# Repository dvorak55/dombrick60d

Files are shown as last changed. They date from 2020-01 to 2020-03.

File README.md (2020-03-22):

# dombrick60d : Dvorak Oriented 60% Keyboard dedicated to Dell
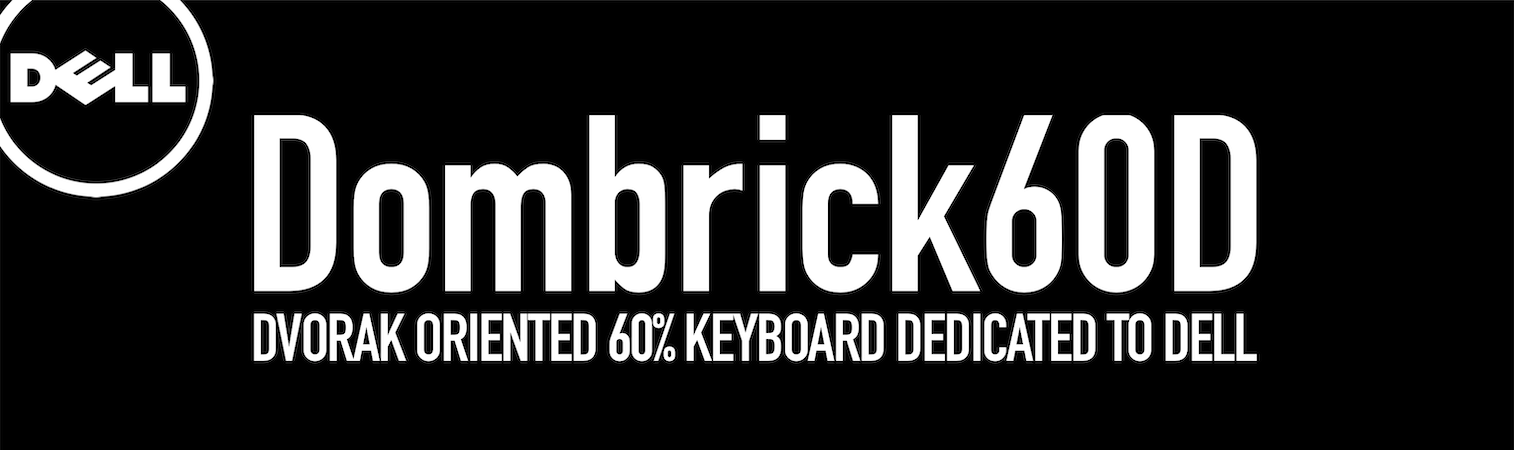
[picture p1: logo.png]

Dombrick60D is self made dvorak oriented keyboard.  
Dombrick60DはDvorak配列志向の自作キーボードです。

"Dombrick" stands for Dvorak Oriented Mechanical Breakthough Remakable Interesting Coolest Keyboard (joke  
Dombrickという名前は「Dvorak志向の革新的で驚くべき大変興味深い最高にクールな機械式キーボード」を表す英単語の頭文字を取って命名しました（笑

Actually, "Dombri" means one of a japanese food style bowl, "ck" means nothing.  
嘘です、Dombriはもちろん日本語の丼を意味しており、ckの二文字はバランスを整えるために付けているだけです。

以下、[DescriptionのPDF](https://github.com/dvorak55/dombrick60d/blob/master/description.pdf)から抜粋

## 概要
Dombrick60DはDvorak配列志向の45%キーボードDombrick45にDellのノートパソコンで採用されていたカーソルキー／PGUP／PGDWを追加、かつマクロ用Chocキーを手前に配置した変態配列キーボードです。

## 特徴
- 横幅14.75U。相変わらずDvorak配列ユーザ志向のキーマップ
- 数字キーが無いのに60%キーボードを名乗る図々しさ
- +と=キーを本来の位置に搭載、カーソルキーもあの位置に搭載
- 最下段の下段(?)にマクロ・ショートカット用のキーを10個搭載
- 一応6.25uスペースバーも選べる(けど作者は使いません)
- モビロンバンドとシリコンマットによるマウント方式は健在だよ! • (最下段の下段以外は)一般的なキーキャップに対応
- DellのPCが使いたくなるPCBシルクデザイン(ロゴを入れただけ)

## キー配列
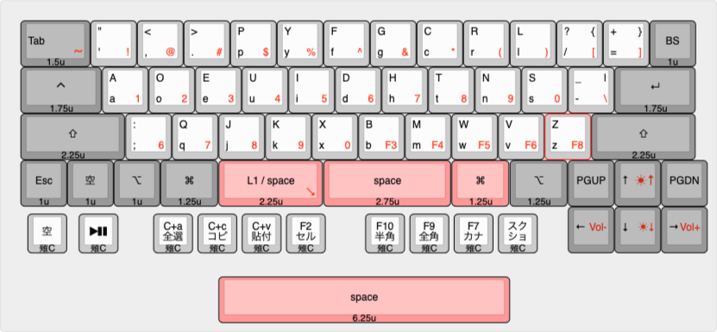
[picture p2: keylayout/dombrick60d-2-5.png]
keymap-of-dombrick60d


最下段のさらに下段（？）の10キーはChoc。Chocなのでスペースキーを押す時に干渉しない、はずなんです。

## Kitに入っている部品
1. PCB 1枚
2. 電子部品(コンデンサ 6個、ダイオード 65個、フューズ 1個、抵抗 6個、ESDダイオード 1個、水晶振動子 1個、リセットスイッチ 1個)
3. MCU(ATmega32U2 1個)
4. USB端子(USB-C 1個)
5. スタビライザー(2Uと6.25Uがそれぞれ 1個ずつ)
6. モビロンゴム(55mm 12本、100mm 6本)
7. シリコンシート(基板サイズ 2枚分)
8. ボトムプレート(厚さ1.5mmステンレス 1枚)

## 別途ご用意頂く部品
1. キースイッチ(Cherry MX互換で5ピンPCBマウント) 53個
2. キースイッチ(Choc) 10個
3. キーキャップ(Cherry MX互換 53個、Choc 10個)
4. USB-Cケーブル

## スペック（実装例）
サイズ：77mm × 253mm × 23mm

重さ　：約560グラム

## スイッチ互換性
Cherry MX互換とALPS(ただし最下段 の下段キーはChoc)

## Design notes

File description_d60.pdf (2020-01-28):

# Dombrick60DはDvorak配列志向の45％キーボード Dombrick45にDellのノートパソコンで採⽤されてい たカーソルキー/PGUP/PGDW追加、かつマクロ⽤ Chocキーを⼿前に配置した変態配列キーボードです

## Dombrick60Dの特徴

### - 横幅14.75U。相変わらずDvorak配列ユーザ志向のキーマップ - 数字キーが無いのに60%キーボードを名乗る図々しさ - +と=キーを本来の位置に搭載、カーソルキーもあの位置に搭載 - 最下段の下段(？)にマクロ・ショートカット⽤のキーを10個搭載 - ⼀応6.25uスペースバーも選べる（けど作者は使いません） - モビロンバンドとシリコンマットによるマウント⽅式は健在だよ！ - （最下段の下段以外は）⼀般的なキーキャップに対応 - DellのPCが使いたくなるPCBシルクデザイン（ロゴを⼊れただけ）

# Dombrick60D

# DVORAK ORIENTED 60% KEYBOARD DEDICATED TO DELL

### Dombrick60DKitに⼊っている部品

1. PCB1枚
2. 電⼦部品(コンデンサ6個、ダイオード65個、フューズ 1個、抵抗6個、ESDダイオード1個、⽔晶振動⼦1 個、リセットスイッチ1個)
3. MCU(ATmega32U21個)
4. USB端⼦(USB-C1個)
5. スタビライザー(2Uと6.25Uがそれぞれ1個ずつ)
6. モビロンゴム(55mm12本、100mm6本)
7. シリコンシート(基板サイズ2枚分)
8. ボトムプレート(厚さ1.5mmステンレス 1枚)

### スペック(実装例)

サイズ：96mm×281mm×22mm 重さ：約???グラム

### スイッチ互換性

CherryMX互換とALPS(ただし最下段
の下段キーはChoc)

### 別途ご⽤意頂く部品

1. キースイッチ(CherryMX互換で5
ピンPCBマウント)53個
2. キースイッチ(Choc）10個
3. キーキャップ(CherryMX互換53
個、Choc10個)
4. USB-Cケーブル

# Dombrick60DはDvorak配列志向の45％キーボード Dombrick45にDellのノートパソコンで採⽤されてい たカーソルキー/PGUP/PGDW追加、かつマクロ⽤ Chocキーを⼿前に配置した変態配列キーボードです

## Dombrick60Dの特徴

### - 横幅14.75U。相変わらずDvorak配列ユーザ志向のキーマップ - 数字キーが無いのに60%キーボードを名乗る図々しさ - +と=キーを本来の位置に搭載、カーソルキーもあの位置に搭載 - 最下段の下段(？)にマクロ・ショートカット⽤のキーを10個搭載 - ⼀応6.25uスペースバーも選べる（けど作者は使いません） - モビロンバンドとシリコンマットによるマウント⽅式は健在だよ！ - （最下段の下段以外は）⼀般的なキーキャップに対応 - DellのPCが使いたくなるPCBシルクデザイン（ロゴを⼊れただけ）

# Dombrick60D

# DVORAK ORIENTED 60% KEYBOARD DEDICATED TO DELL

### Dombrick60DKitに⼊っている部品

1. PCB1枚
2. 電⼦部品(コンデンサ6個、ダイオード65個、フューズ 1個、抵抗6個、ESDダイオード1個、⽔晶振動⼦1 個、リセットスイッチ1個)
3. MCU(ATmega32U21個)
4. USB端⼦(USB-C1個)
5. スタビライザー(2Uと6.25Uがそれぞれ1個ずつ)
6. モビロンゴム(55mm12本、100mm6本)
7. シリコンシート(基板サイズ2枚分)
8. ボトムプレート(厚さ1.5mmステンレス 1枚)

### スペック(実装例)

サイズ：96mm×281mm×22mm 重さ：約???グラム

### スイッチ互換性

CherryMX互換とALPS(ただし最下段
の下段キーはChoc)

### 別途ご⽤意頂く部品

1. キースイッチ(CherryMX互換で5
ピンPCBマウント)53個
2. キースイッチ(Choc）10個
3. キーキャップ(CherryMX互換53
個、Choc10個)
4. USB-Cケーブル

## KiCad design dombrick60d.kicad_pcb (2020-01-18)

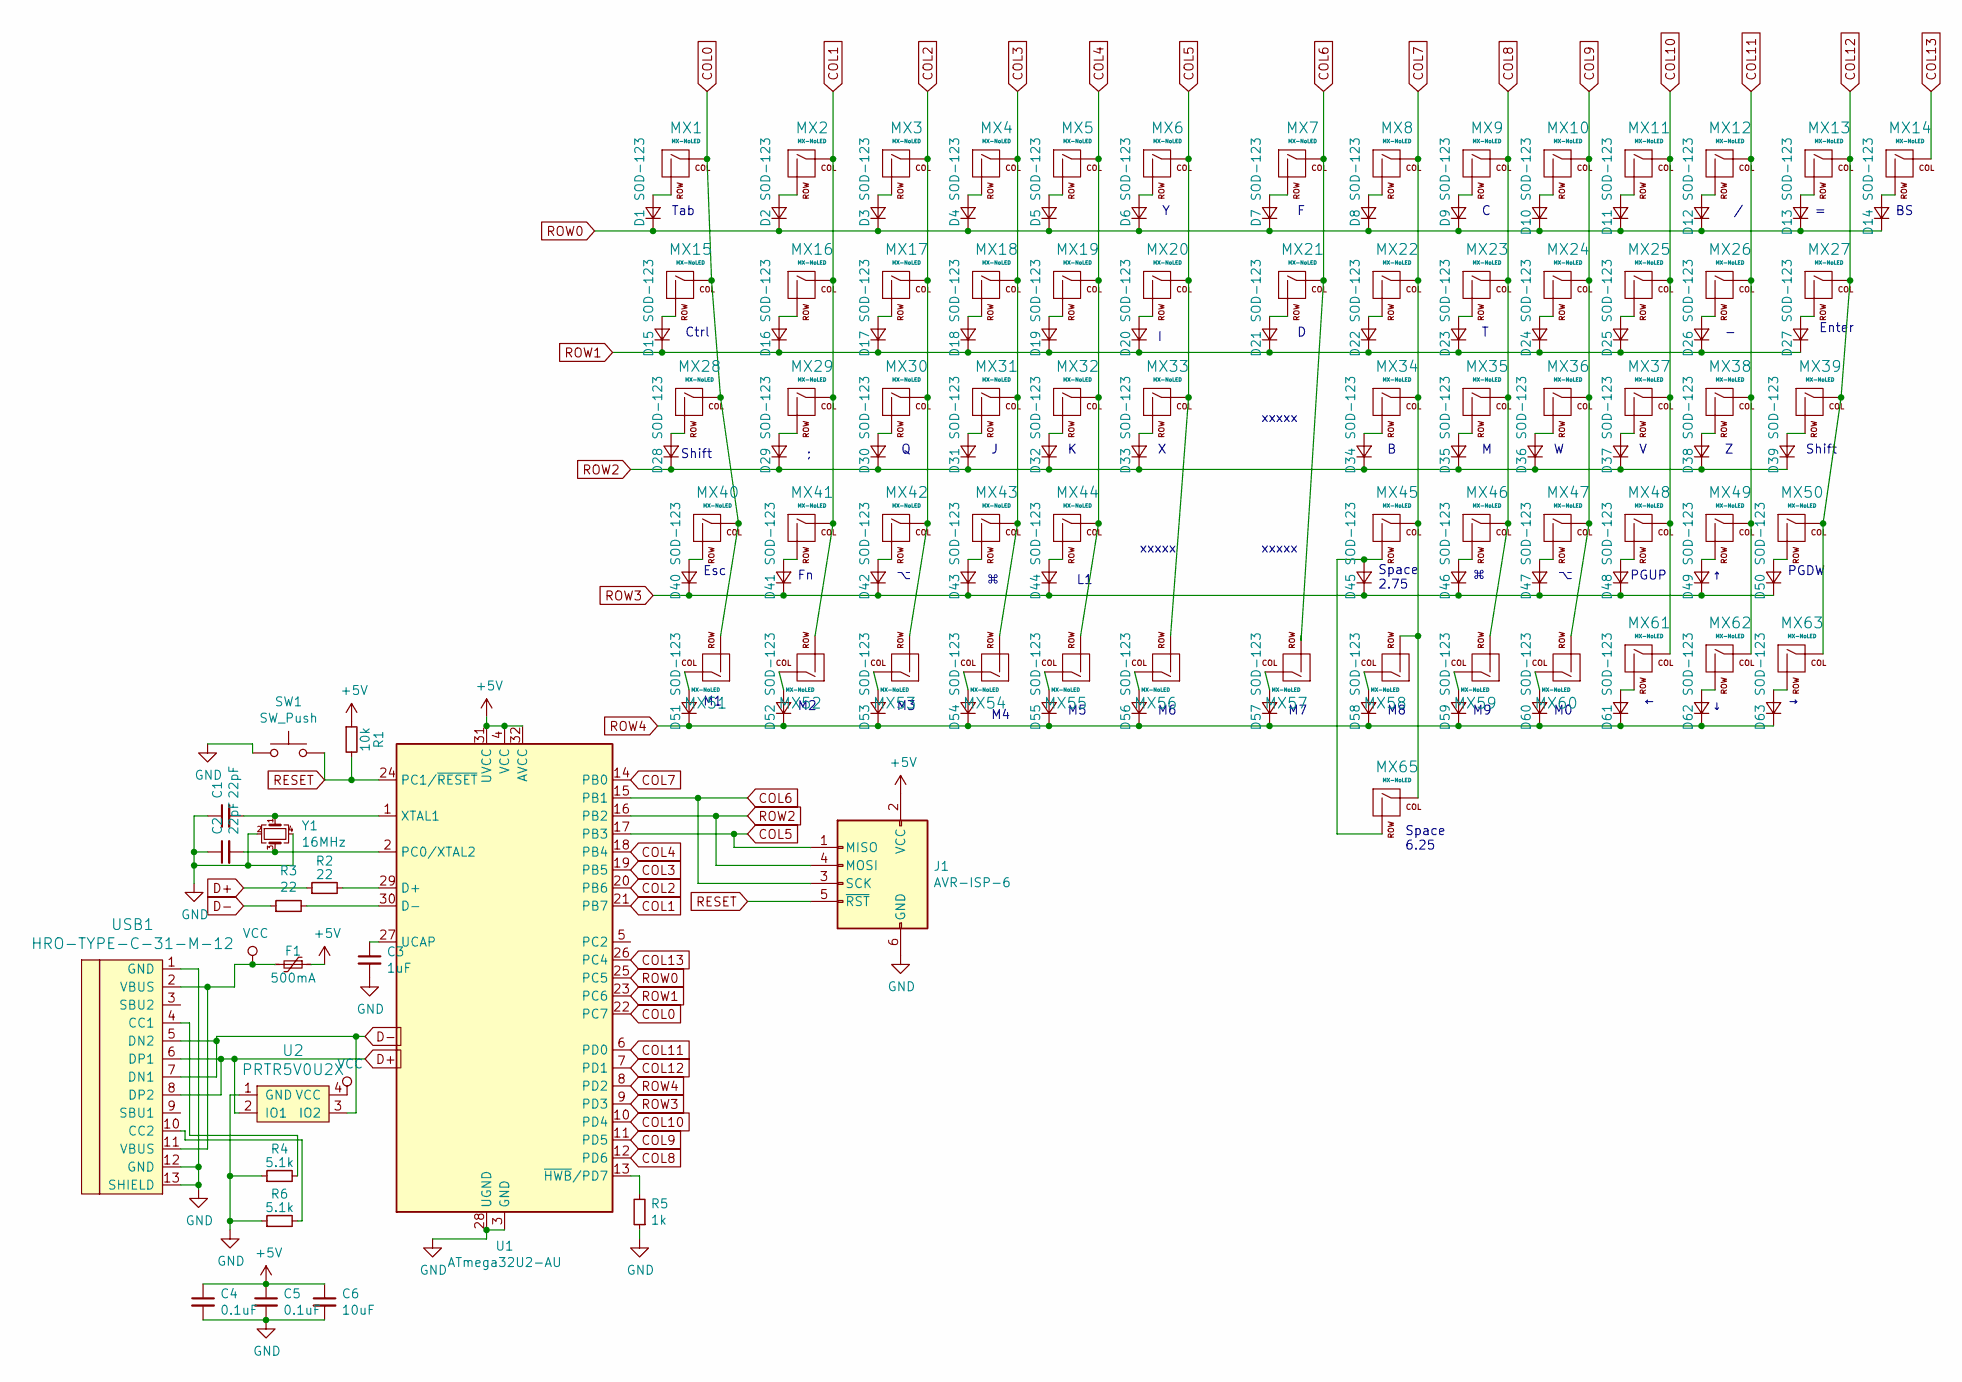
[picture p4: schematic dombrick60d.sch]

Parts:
C1, C2: 22pF; C_0805_2012Metric_Pad1.15x1.40mm_HandSolder
C3: 1uF; C_0805_2012Metric_Pad1.15x1.40mm_HandSolder
C4, C5: 0.1uF; C_0805_2012Metric_Pad1.15x1.40mm_HandSolder
C6: 10uF; C_0805_2012Metric_Pad1.15x1.40mm_HandSolder
D1, D2, D3, D4, D5, D6, D7, D8, D9, D10, D11, D12, D13, D14, D15, D16, D17, D18, D19, D20, D21, D22, D23, D24, D25, D26, D27, D28, D29, D30, D31, D32, D33, D34, D35, D36, D37, D38, D39, D40, D41, D42, D43, D44, D45, D46, D47, D48, D49, D50, D51, D52, D53, D54, D55, D56, D57, D58, D59, D60, D61, D62, D63: SOD-123; D_SOD-123
F1: 500mA; Fuse_1206_3216Metric_Pad1.42x1.75mm_HandSolder
J1: AVR-ISP-6; Reset_Pretty
MX1: MX-NoLED; MX-1.5U-NoLED
MX2, MX3, MX4, MX5, MX6, MX7, MX8, MX9, MX10, MX11, MX12, MX13, MX14, MX16, MX17, MX18, MX19, MX20, MX21, MX22, MX23, MX24, MX25, MX26, MX29, MX30, MX31, MX32, MX33, MX34, MX35, MX36, MX37, MX38, MX40, MX41, MX42, MX48, MX49, MX50, MX61, MX62, MX63: MX-NoLED; MX-1U-NoLED
MX15, MX27: MX-NoLED; MX-1.75U-NoLED
MX28, MX39, MX44: MX-NoLED; MX-2.25U-NoLED
MX43, MX46, MX47: MX-NoLED; MX-1.25U-NoLED
MX45: MX-NoLED; MX-2.75U-NoLED
MX51, MX52, MX53, MX54, MX55, MX56, MX57, MX58, MX59, MX60: MX-NoLED; KailhChoc-1U
MX65: MX-NoLED; MX-6.25U-NoLED
R1: 10k; R_0805_2012Metric
R2, R3: 22; R_0805_2012Metric
R4, R6: 5.1k; R_0805_2012Metric
R5: 1k; R_0805_2012Metric
SW1: SW_Push; SKQG-1155865
U1: ATmega32U2-AU; TQFP-32_7x7mm_P0.8mm
U2: PRTR5V0U2X; SOT143B
USB1: HRO-TYPE-C-31-M-12; HRO-TYPE-C-31-M-12-Assembly
Y1: 16MHz; Crystal_SMD_3225-4Pin_3.2x2.5mm

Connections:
+5V: C4.1, C5.1, C6.1, F1.1, J1.2 (VCC), R1.1, U1.4 (VCC), U1.31 (UVCC), U1.32 (AVCC)
COL0: MX1.1 (COL), MX15.1 (COL), MX28.1 (COL), MX40.1 (COL), MX51.2 (ROW), U1.22 (PC7)
COL1: MX2.1 (COL), MX16.1 (COL), MX29.1 (COL), MX41.1 (COL), MX52.2 (ROW), U1.21 (PB7)
COL2: MX3.1 (COL), MX17.1 (COL), MX30.1 (COL), MX42.1 (COL), MX53.2 (ROW), U1.20 (PB6)
COL3: MX4.1 (COL), MX18.1 (COL), MX31.1 (COL), MX43.1 (COL), MX54.2 (ROW), U1.19 (PB5)
COL4: MX5.1 (COL), MX19.1 (COL), MX32.1 (COL), MX44.1 (COL), MX55.2 (ROW), U1.18 (PB4)
COL5: J1.1 (MISO), MX6.1 (COL), MX20.1 (COL), MX33.1 (COL), MX56.2 (ROW), U1.17 (PB3)
COL6: J1.3 (SCK), MX7.1 (COL), MX21.1 (COL), MX57.2 (ROW), U1.15 (PB1)
COL7: MX8.1 (COL), MX22.1 (COL), MX34.1 (COL), MX45.1 (COL), MX58.2 (ROW), MX65.1 (COL), U1.14 (PB0)
COL8: MX9.1 (COL), MX23.1 (COL), MX35.1 (COL), MX46.1 (COL), MX59.2 (ROW), U1.12 (PD6)
COL9: MX10.1 (COL), MX24.1 (COL), MX36.1 (COL), MX47.1 (COL), MX60.2 (ROW), U1.11 (PD5)
COL10: MX11.1 (COL), MX25.1 (COL), MX37.1 (COL), MX48.1 (COL), MX61.1 (COL), U1.10 (PD4)
COL11: MX12.1 (COL), MX26.1 (COL), MX38.1 (COL), MX49.1 (COL), MX62.1 (COL), U1.6 (PD0)
COL12: MX13.1 (COL), MX27.1 (COL), MX39.1 (COL), MX50.1 (COL), MX63.1 (COL), U1.7 (PD1)
COL13: MX14.1 (COL), U1.26 (PC4)
D+: R2.1, U2.2 (IO1), USB1.6 (DP1), USB1.8 (DP2)
D-: R3.1, U2.3 (IO2), USB1.5 (DN2), USB1.7 (DN1)
GND: C1.1, C2.1, C3.2, C4.2, C5.2, C6.2, J1.6 (GND), R4.1, R5.1, R6.1, SW1.1, U1.3 (GND), U1.28 (UGND), U2.1 (GND), USB1.1 (GND), USB1.12 (GND), USB1.13 (SHIELD), Y1.2, Y1.4
unnamed: C1.2, U1.1 (XTAL1), Y1.1
unnamed: C2.2, U1.2 (PC0/XTAL2), Y1.3
unnamed: C3.1, U1.27 (UCAP)
unnamed: D1.2 (A), MX1.2 (ROW)
unnamed: D2.2 (A), MX2.2 (ROW)
unnamed: D3.2 (A), MX3.2 (ROW)
unnamed: D4.2 (A), MX4.2 (ROW)
unnamed: D5.2 (A), MX5.2 (ROW)
unnamed: D6.2 (A), MX6.2 (ROW)
unnamed: D7.2 (A), MX7.2 (ROW)
unnamed: D8.2 (A), MX8.2 (ROW)
unnamed: D9.2 (A), MX9.2 (ROW)
unnamed: D10.2 (A), MX10.2 (ROW)
unnamed: D11.2 (A), MX11.2 (ROW)
unnamed: D12.2 (A), MX12.2 (ROW)
unnamed: D13.2 (A), MX13.2 (ROW)
unnamed: D14.2 (A), MX14.2 (ROW)
unnamed: D15.2 (A), MX15.2 (ROW)
unnamed: D16.2 (A), MX16.2 (ROW)
unnamed: D17.2 (A), MX17.2 (ROW)
unnamed: D18.2 (A), MX18.2 (ROW)
unnamed: D19.2 (A), MX19.2 (ROW)
unnamed: D20.2 (A), MX20.2 (ROW)
unnamed: D21.2 (A), MX21.2 (ROW)
unnamed: D22.2 (A), MX22.2 (ROW)
unnamed: D23.2 (A), MX23.2 (ROW)
unnamed: D24.2 (A), MX24.2 (ROW)
unnamed: D25.2 (A), MX25.2 (ROW)
unnamed: D26.2 (A), MX26.2 (ROW)
unnamed: D27.2 (A), MX27.2 (ROW)
unnamed: D28.2 (A), MX28.2 (ROW)
unnamed: D29.2 (A), MX29.2 (ROW)
unnamed: D30.2 (A), MX30.2 (ROW)
unnamed: D31.2 (A), MX31.2 (ROW)
unnamed: D32.2 (A), MX32.2 (ROW)
unnamed: D33.2 (A), MX33.2 (ROW)
unnamed: D34.2 (A), MX34.2 (ROW)
unnamed: D35.2 (A), MX35.2 (ROW)
unnamed: D36.2 (A), MX36.2 (ROW)
unnamed: D37.2 (A), MX37.2 (ROW)
unnamed: D38.2 (A), MX38.2 (ROW)
unnamed: D39.2 (A), MX39.2 (ROW)
unnamed: D40.2 (A), MX40.2 (ROW)
unnamed: D41.2 (A), MX41.2 (ROW)
unnamed: D42.2 (A), MX42.2 (ROW)
unnamed: D43.2 (A), MX43.2 (ROW)
unnamed: D44.2 (A), MX44.2 (ROW)
unnamed: D45.2 (A), MX45.2 (ROW), MX65.2 (ROW)
unnamed: D46.2 (A), MX46.2 (ROW)
unnamed: D47.2 (A), MX47.2 (ROW)
unnamed: D48.2 (A), MX48.2 (ROW)
unnamed: D49.2 (A), MX49.2 (ROW)
unnamed: D50.2 (A), MX50.2 (ROW)
unnamed: D51.2 (A), MX51.1 (COL)
unnamed: D52.2 (A), MX52.1 (COL)
unnamed: D53.2 (A), MX53.1 (COL)
unnamed: D54.2 (A), MX54.1 (COL)
unnamed: D55.2 (A), MX55.1 (COL)
unnamed: D56.2 (A), MX56.1 (COL)
unnamed: D57.2 (A), MX57.1 (COL)
unnamed: D58.2 (A), MX58.1 (COL)
unnamed: D59.2 (A), MX59.1 (COL)
unnamed: D60.2 (A), MX60.1 (COL)
unnamed: D61.2 (A), MX61.2 (ROW)
unnamed: D62.2 (A), MX62.2 (ROW)
unnamed: D63.2 (A), MX63.2 (ROW)
unnamed: R2.2, U1.29 (D+)
unnamed: R3.2, U1.30 (D-)
unnamed: R4.2, USB1.4 (CC1)
unnamed: R5.2, U1.13 (~HWB~/PD7)
unnamed: R6.2, USB1.10 (CC2)
RESET: J1.5 (~RST), R1.2, SW1.2, U1.24 (PC1/~RESET)
ROW0: D1.1 (K), D2.1 (K), D3.1 (K), D4.1 (K), D5.1 (K), D6.1 (K), D7.1 (K), D8.1 (K), D9.1 (K), D10.1 (K), D11.1 (K), D12.1 (K), D13.1 (K), D14.1 (K), U1.25 (PC5)
ROW1: D15.1 (K), D16.1 (K), D17.1 (K), D18.1 (K), D19.1 (K), D20.1 (K), D21.1 (K), D22.1 (K), D23.1 (K), D24.1 (K), D25.1 (K), D26.1 (K), D27.1 (K), U1.23 (PC6)
ROW2: D28.1 (K), D29.1 (K), D30.1 (K), D31.1 (K), D32.1 (K), D33.1 (K), D34.1 (K), D35.1 (K), D36.1 (K), D37.1 (K), D38.1 (K), D39.1 (K), J1.4 (MOSI), U1.16 (PB2)
ROW3: D40.1 (K), D41.1 (K), D42.1 (K), D43.1 (K), D44.1 (K), D45.1 (K), D46.1 (K), D47.1 (K), D48.1 (K), D49.1 (K), D50.1 (K), U1.9 (PD3)
ROW4: D51.1 (K), D52.1 (K), D53.1 (K), D54.1 (K), D55.1 (K), D56.1 (K), D57.1 (K), D58.1 (K), D59.1 (K), D60.1 (K), D61.1 (K), D62.1 (K), D63.1 (K), U1.8 (PD2)
VCC: F1.2, U2.4 (VCC), USB1.2 (VBUS), USB1.11 (VBUS)

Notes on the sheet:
Space 2.75
PGDW
Enter
Tab
Esc
Shift
Ctrl
PGUP
xxxxx
Space 6.25

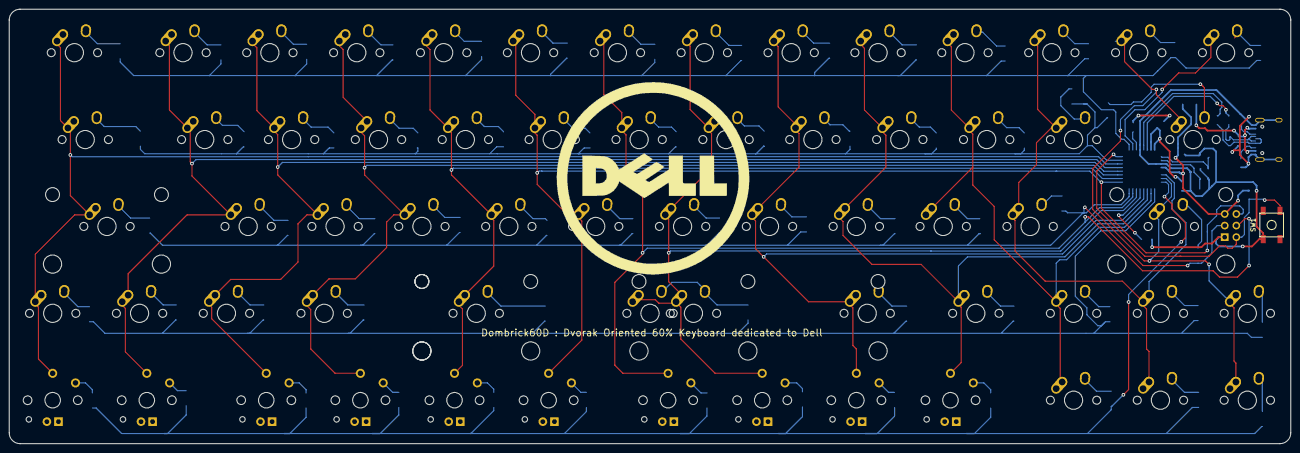
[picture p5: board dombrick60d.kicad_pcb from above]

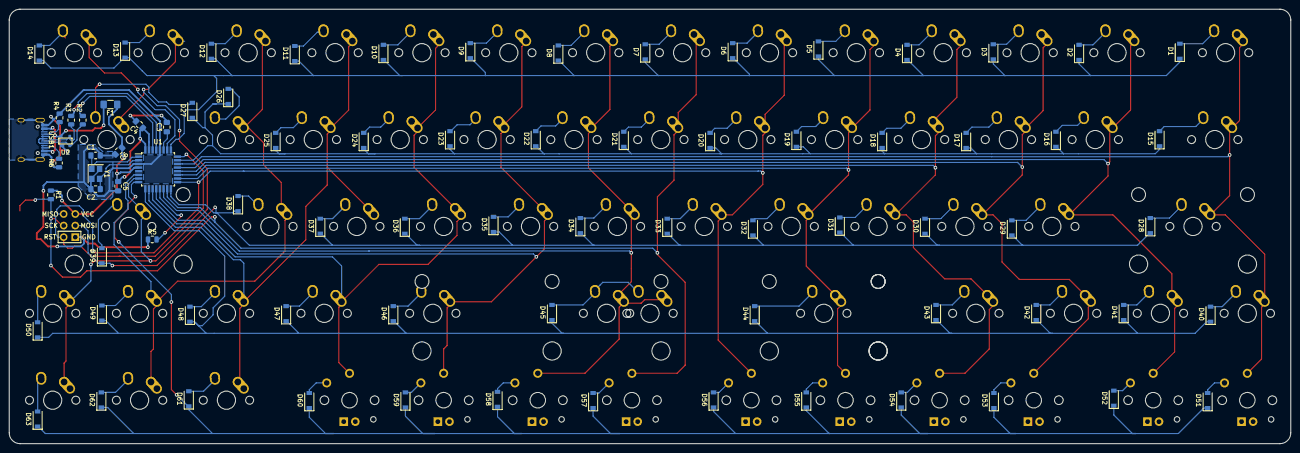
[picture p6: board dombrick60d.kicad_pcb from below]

Board: 2 copper layers, 281.0 x 95.3 mm, 146 parts (81 on the bottom side), 96 nets.

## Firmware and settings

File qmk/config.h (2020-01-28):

/*
Copyright 2020 t-miyajima

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
You should have received a copy of the GNU General Public License
along with this program.  If not, see <http://www.gnu.org/licenses/>.
*/

#pragma once

#include "config_common.h"

/* USB Device descriptor parameter */
#define VENDOR_ID 0xFEED
#define PRODUCT_ID 0x0001
#define DEVICE_VER 0x0001
#define MANUFACTURER t-miyajima
#define PRODUCT Dombrick60D
#define DESCRIPTION Dvorak Oriented Mechanical Breakthough Remakable Interesting Coolest Keyboard dedicated to Dell

/* t-miyajima usb power settings arrenge */
#define USB_MAX_POWER_CONSUMPTION 100
#define USB_DEVICE_POWER 100

/* key matrix size */
#define MATRIX_ROWS 5
#define MATRIX_COLS 14

/*
 * Keyboard Matrix Assignments
 *
 * Change this to how you wired your keyboard
 * COLS: AVR pins used for columns, left to right
 * ROWS: AVR pins used for rows, top to bottom
 * DIODE_DIRECTION: COL2ROW = COL = Anode (+), ROW = Cathode (-, marked on diode)
 *                  ROW2COL = ROW = Anode (+), COL = Cathode (-, marked on diode)
 *
 */
#define MATRIX_ROW_PINS { C5, C6, B2, D3, D2 }
#define MATRIX_COL_PINS { C7, B7, B6, B5, B4, B3, B1, B0, D6, D5, D4, D0, D1, C4 }
#define UNUSED_PINS

/* COL2ROW, ROW2COL*/
#define DIODE_DIRECTION COL2ROW

/*
 * Split Keyboard specific options, make sure you have 'SPLIT_KEYBOARD = yes' in your rules.mk, and define SOFT_SERIAL_PIN.
 */
#define SOFT_SERIAL_PIN D0  // or D1, D2, D3, E6

// #define BACKLIGHT_PIN B7
// #define BACKLIGHT_BREATHING
// #define BACKLIGHT_LEVELS 3

// #define RGB_DI_PIN E2
// #ifdef RGB_DI_PIN
//   #define RGBLED_NUM 16
//   #define RGBLIGHT_HUE_STEP 8
//   #define RGBLIGHT_SAT_STEP 8
//   #define RGBLIGHT_VAL_STEP 8
//   #define RGBLIGHT_LIMIT_VAL 255 /* The maximum brightness level */
//   #define RGBLIGHT_SLEEP  /* If defined, the RGB lighting will be switched off when the host goes to sleep */
// /*== all animations enable ==*/
//   #define RGBLIGHT_ANIMATIONS
// /*== or choose animations ==*/
//   #define RGBLIGHT_EFFECT_BREATHING
//   #define RGBLIGHT_EFFECT_RAINBOW_MOOD
//   #define RGBLIGHT_EFFECT_RAINBOW_SWIRL
//   #define RGBLIGHT_EFFECT_SNAKE
//   #define RGBLIGHT_EFFECT_KNIGHT
//   #define RGBLIGHT_EFFECT_CHRISTMAS
//   #define RGBLIGHT_EFFECT_STATIC_GRADIENT
//   #define RGBLIGHT_EFFECT_RGB_TEST
//   #define RGBLIGHT_EFFECT_ALTERNATING
// /*== customize breathing effect ==*/
//   /*==== (DEFAULT) use fixed table instead of exp() and sin() ====*/
//   #define RGBLIGHT_BREATHE_TABLE_SIZE 256      // 256(default) or 128 or 64
//   /*==== use exp() and sin() ====*/
//   #define RGBLIGHT_EFFECT_BREATHE_CENTER 1.85  // 1 to 2.7
//   #define RGBLIGHT_EFFECT_BREATHE_MAX    255   // 0 to 255
// #endif

/* Debounce reduces chatter (unintended double-presses) - set 0 if debouncing is not needed */
#define DEBOUNCE 5

/* define if matrix has ghost (lacks anti-ghosting diodes) */
//#define MATRIX_HAS_GHOST

/* Mechanical locking support. Use KC_LCAP, KC_LNUM or KC_LSCR instead in keymap */
#define LOCKING_SUPPORT_ENABLE
/* Locking resynchronize hack */
#define LOCKING_RESYNC_ENABLE

/* If defined, GRAVE_ESC will always act as ESC when CTRL is held.
 * This is userful for the Windows task manager shortcut (ctrl+shift+esc).
 */
// #define GRAVE_ESC_CTRL_OVERRIDE

/*
 * Force NKRO
 *
 * Force NKRO (nKey Rollover) to be enabled by default, regardless of the saved
 * state in the bootmagic EEPROM settings. (Note that NKRO must be enabled in the
 * makefile for this to work.)
 *
 * If forced on, NKRO can be disabled via magic key (default = LShift+RShift+N)
 * until the next keyboard reset.
 *
 * NKRO may prevent your keystrokes from being detected in the BIOS, but it is
 * fully operational during normal computer usage.
 *
 * For a less heavy-handed approach, enable NKRO via magic key (LShift+RShift+N)
 * or via bootmagic (hold SPACE+N while plugging in the keyboard). Once set by
 * bootmagic, NKRO mode will always be enabled until it is toggled again during a
 * power-up.
 *
 */
//#define FORCE_NKRO

/*
 * Magic Key Options
 *
 * Magic keys are hotkey commands that allow control over firmware functions of
 * the keyboard. They are best used in combination with the HID Listen program,
 * found here: https://www.pjrc.com/teensy/hid_listen.html
 *
 * The options below allow the magic key functionality to be changed. This is
 * useful if your keyboard/keypad is missing keys and you want magic key support.
 *
 */

/* key combination for magic key command */
/* defined by default; to change, uncomment and set to the combination you want */
// #define IS_COMMAND() (get_mods() == MOD_MASK_SHIFT)

/* control how magic key switches layers */
//#define MAGIC_KEY_SWITCH_LAYER_WITH_FKEYS  true
//#define MAGIC_KEY_SWITCH_LAYER_WITH_NKEYS  true
//#define MAGIC_KEY_SWITCH_LAYER_WITH_CUSTOM false
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

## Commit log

2020-01-14 create kicad pro
    [dombrick60d.kicad_pcb, dombrick60d.sch]
2020-01-14 Add footprint libraries
2020-01-15 add usb-c footprint libraries
2020-01-15 sch tabun done
    [dombrick45.sch]
2020-01-15 sugee ganbatta
    [dombrick60d.sch]
2020-01-18 sugoku ganbatta
    [dombrick60d.kicad_pcb, dombrick60d.sch]
2020-01-18 pcb haisen ok
    [dombrick60d.kicad_pcb]
2020-01-18 2020-01-19 all ok lets production start
    [dombrick60d.kicad_pcb, dombrick60d.sch]
2020-01-18 gerber generate done
    [dombrick60d-B_Cu.gbl, dombrick60d-B_Mask.gbs, dombrick60d-B_SilkS.gbo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]
2020-01-28 2020年1月29日
    logo toka tuika shita
2020-01-30 create readme.md
    DELLに怒られたらどうしようと怯えるようでは駄目
2020-02-14 2020-02-15 dombrick60d finish!!
    Dombrick60Dが完成しました。
    嬉しい。

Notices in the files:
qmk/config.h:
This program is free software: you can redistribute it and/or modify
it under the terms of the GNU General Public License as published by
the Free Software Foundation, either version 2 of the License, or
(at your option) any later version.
